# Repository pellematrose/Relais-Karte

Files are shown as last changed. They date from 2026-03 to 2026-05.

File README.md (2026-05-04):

# Relais-Karte

Relais-Karte für 24V-Systeme, zum schalten von induktiven Lasten.

---

## 🔧 Gedachte Verwendung

Über **J1** wird die Schaltung mit Strom versorgt.  
Über **J2** kann eine weitere Platine mit Spannung versorgt werden.

Eine **Autosicherung** schützt die Schaltung bzw. die angeschlossene Last.

Der **Schiebeschalter** ermöglicht es, die Last **unabhängig vom Relais** einzuschalten.

---

## 💡 Statusanzeigen (LEDs)

Die Platine verfügt über **zwei LEDs zur Zustandsanzeige**:

- **LED 1 – Versorgung & Sicherung OK**  
  - Leuchtet, wenn **Spannung anliegt** und die **Sicherung in Ordnung** ist

- **LED 2 – Relais aktiv / Last versorgt**  
  - Leuchtet, wenn das **Relais geschaltet hat** oder der **manuelle Schalter** eingeschaltet ist  
  - → Die angeschlossene **Last erhält Spannung**

---

## ⚙️ Relaissteuerung

An **J4** wird das **Schaltsignal** angeschlossen, mit dem das Relais aktiviert wird.  
Hier kann z. B. ein **Schwimmerschalter** als Schließer verwendet werden.  
Wird ein anderes externes Schaltsignal verwendet, muss auf den GND Pfad geachtet werden!

---

## 🔌 Anschluss der Last

Die Last (z. B. eine **Pumpe**) wird an **J3** angeschlossen.

### Betriebsarten:

- **Relais schaltet EIN (NO - Normally Open):**  
  - Last zwischen **NO (+24V)** und **GND** anschließen  
  - → Last ist aktiv, wenn das Relais angezogen ist

- **Relais schaltet AUS (NC - Normally Closed):**  
  - Last zwischen **NC (+24V)** und **GND** anschließen  
  - → Last ist aktiv, wenn das Relais **nicht** angezogen ist

💡 Es können auch **zwei Lasten gleichzeitig angeschlossen** werden:  
- Eine an **NO**
- Eine an **NC**  
→ Es ist dabei **immer nur eine Last aktiv**  
→ Die Last muss **immer** mit **GND** verbunden werden!

### Anschlussplan
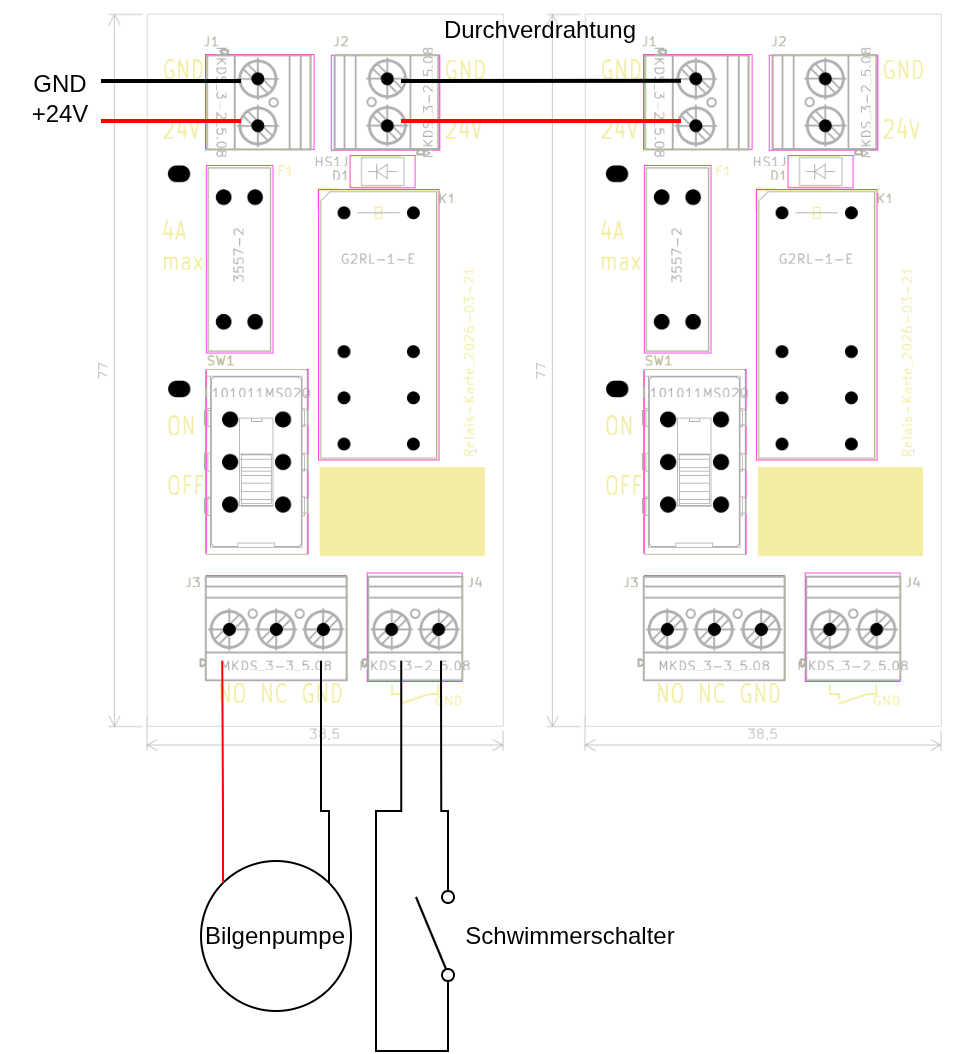
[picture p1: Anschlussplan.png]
Anschlussplan
  

---

## 📝 Sonstiges

Das **weiße Feld** auf der Platine ist für Notizen vorgesehen, z. B.:

- Nummerierung
- Bezeichnung der angeschlossenen Last

---

## 📏 Technische Daten

- Versorgungsspannung: 24V (+-20%)
- Laststrom: 4A (Schiebeschalter, Leiterbahnen)
- **PCB Maße:** 38,5 mm × 77 mm

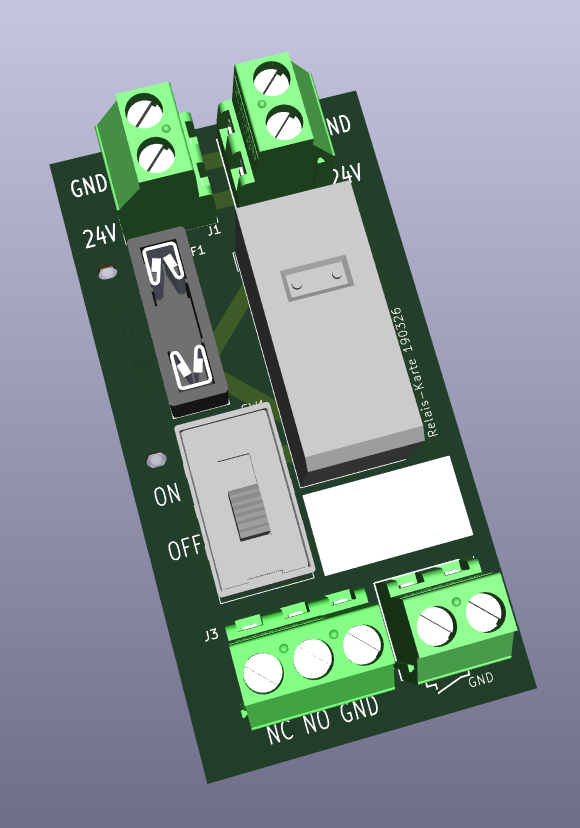
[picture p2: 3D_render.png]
3D Render

---

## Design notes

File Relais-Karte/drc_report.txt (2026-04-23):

** Drc report for Relais-Karte.kicad_pcb **
** Created on 2026-04-23T21:58:57 **
** Report includes: Errors, Warnings **

** Found 4 DRC violations **
[copper_edge_clearance]: Platinenkanten-Freiraum-Verstoß (Einschränkungen aus Platinenkonfiguration zum Rand Freiraum 0,5000 mm; tatsächlich 0,1750 mm)
    Rule: Einschränkungen aus Platinenkonfiguration zum Rand; error
    @(97.9750 mm, 54.2375 mm): NPTH-Pad von D2
    @(97.9750 mm, 52.6875 mm): Pad 1 [GND] von D2 auf B.Cu
[copper_edge_clearance]: Platinenkanten-Freiraum-Verstoß (Einschränkungen aus Platinenkonfiguration zum Rand Freiraum 0,5000 mm; tatsächlich 0,1750 mm)
    Rule: Einschränkungen aus Platinenkonfiguration zum Rand; error
    @(97.9750 mm, 54.2375 mm): NPTH-Pad von D2
    @(97.9750 mm, 55.7875 mm): Pad 2 [Net-(D2-A)] von D2 auf B.Cu
[copper_edge_clearance]: Platinenkanten-Freiraum-Verstoß (Einschränkungen aus Platinenkonfiguration zum Rand Freiraum 0,5000 mm; tatsächlich 0,1750 mm)
    Rule: Einschränkungen aus Platinenkonfiguration zum Rand; error
    @(98.0000 mm, 77.5000 mm): NPTH-Pad von D3
    @(98.0000 mm, 75.9500 mm): Pad 1 [GND] von D3 auf B.Cu
[copper_edge_clearance]: Platinenkanten-Freiraum-Verstoß (Einschränkungen aus Platinenkonfiguration zum Rand Freiraum 0,5000 mm; tatsächlich 0,1750 mm)
    Rule: Einschränkungen aus Platinenkonfiguration zum Rand; error
    @(98.0000 mm, 77.5000 mm): NPTH-Pad von D3
    @(98.0000 mm, 79.0500 mm): Pad 2 [Net-(D3-A)] von D3 auf B.Cu

** Found 0 unconnected pads **

** Found 0 Footprint errors **

** Ignored checks **
    - Footprint has no courtyard defined
    - Track endpoint not centered on via
    - Tuning profile track geometries
    - Footprint doesn't match symbol's footprint filters
    - PTH inside courtyard
    - NPTH inside courtyard
    - Footprint component type doesn't match footprint pads

** End of Report **

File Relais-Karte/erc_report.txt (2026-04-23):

ERC report (2026-04-23T21:58:53, Encoding UTF8)
Report includes: Errors, Warnings

***** Sheet /
[power_pin_not_driven]: Input Power pin not driven by any Output Power pins
    ; warning
    @(69.85 mm, 25.40 mm): Symbol #PWR010 Pin 1 [Stromversorgung, Linie]
[power_pin_not_driven]: Input Power pin not driven by any Output Power pins
    ; warning
    @(162.56 mm, 52.07 mm): Symbol #PWR02 Pin 1 [Stromversorgung, Linie]
[power_pin_not_driven]: Input Power pin not driven by any Output Power pins
    ; warning
    @(212.09 mm, 60.96 mm): Symbol #PWR01 Pin 1 [Stromversorgung, Linie]

 ** ERC messages: 3  Errors 0  Warnings 3

 ** Ignored checks:
    - Global label only appears once in the schematic
    - Four connection points are joined together
    - SPICE model issue
    - Assigned footprint doesn't match footprint filters

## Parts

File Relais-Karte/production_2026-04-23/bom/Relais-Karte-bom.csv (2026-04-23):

Reference | QUANTITY | Value | Footprint | LCSC | Digikey | Mouser
D1,D5,D6 | 3 | HS1J | _PS_LIB_PCB:D_SMA |  | 1801-HS1JCT-ND
D2 | 1 | KPTD-3216ZGCK-01 | _PS_LIB_PCB:LED_1206_3216Metric_ReverseMount_Hole1.8x2.4mm
D3 | 1 | KPTD-3216SYCK-01 | _PS_LIB_PCB:LED_1206_3216Metric_ReverseMount_Hole1.8x2.4mm
D4 | 1 | SMAJ30A | Diode_SMD:D_SMA
F1 | 1 | 3557-2 | _PS_LIB_CON:Fuse Holder Littelfuse ATOF 287 | C19727304 | 36-3557-2-ND
J1,J2,J4 | 3 | MKDS_3-2_5.08 | _PS_LIB_CON:MKDS_3_2_508 | C475092 | 277-1027-ND
J3 | 1 | MKDS_3-3_5.08 | _PS_LIB_CON:MKDS_3_3_508 | C475093 | 277-1028-ND
K1 | 1 | G2RL-1-E | _PS_LIB_PCB:Relay_SPDT_Omron_G2RL-1-E |  | Z2835-ND
Q1,Q2 | 2 | BC846 | Package_TO_SOT_SMD:SOT-23
R1,R4 | 2 | 22K | Resistor_SMD:R_0603_1608Metric | C31850
R2 | 1 | 10K | Resistor_SMD:R_0603_1608Metric | C25804
R3 | 1 | 4K7 | Resistor_SMD:R_0603_1608Metric | C23162
R5 | 1 | 100K | Resistor_SMD:R_0603_1608Metric | C25803
SW1 | 1 | L101011MS02Q | _PS_LIB_MECH:L10101_Schiebeschalter |  | CKC5106-ND
U1,U2 | 2 | TS431ACX RF | Package_TO_SOT_SMD:SOT-23 |  |  | 821-TS431ACXRFG

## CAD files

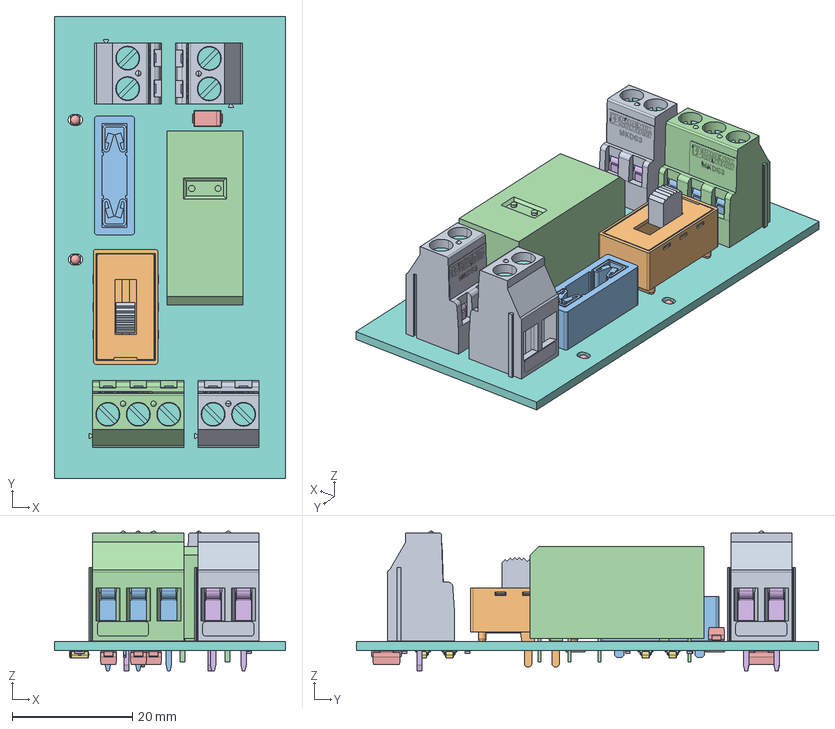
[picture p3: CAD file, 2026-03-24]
Relais-Karte/production_2026-03-24/step/Relais-Karte.step
38.5 x 77.0 x 23.3 mm
L101011MS02Q_PART1
G2RL-1-E DC24
D_SMA x 4
Bohrloch.2 x 3
Klemmhülse_1 x 3
Schraube_2 x 3
Druckstück_2 x 3
MKDS_3_3-5.08_GEH
KPTD-3216SECK x 2
R_0603_1608Metric x 5
SOT-23 x 4
Relais-Karte_PCB

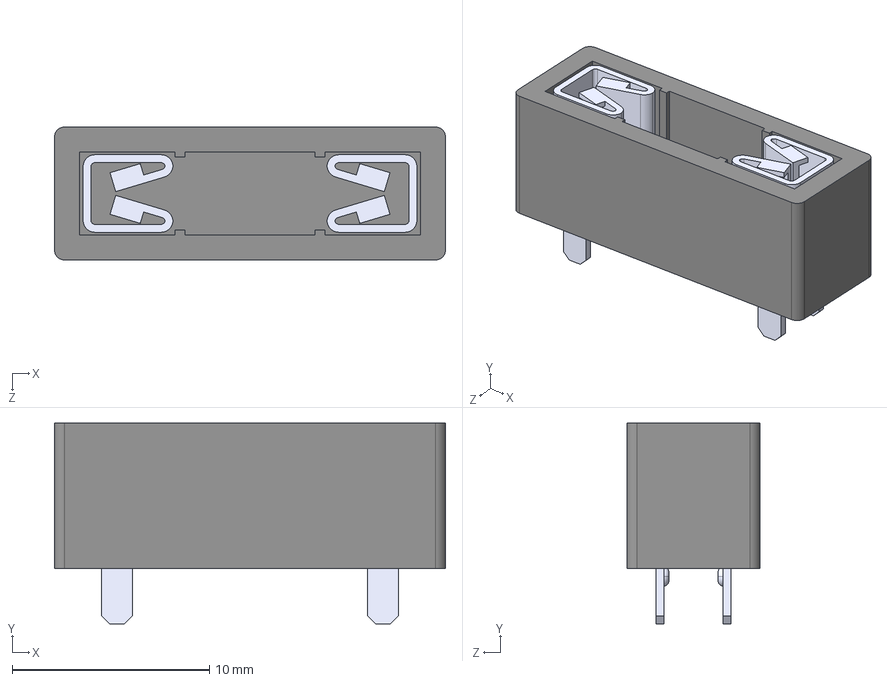
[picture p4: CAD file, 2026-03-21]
Relais-Karte/source_2026-04-23/3dmodels/3557-2.step
19.8 x 10.2 x 6.73 mm

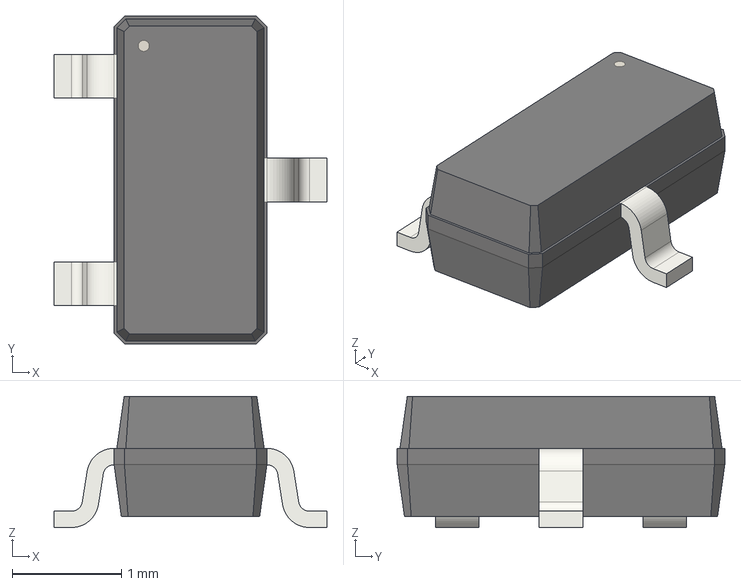
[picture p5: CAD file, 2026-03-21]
Relais-Karte/source_2026-04-23/3dmodels/SOT-23.step
2.50 x 3.00 x 1.20 mm

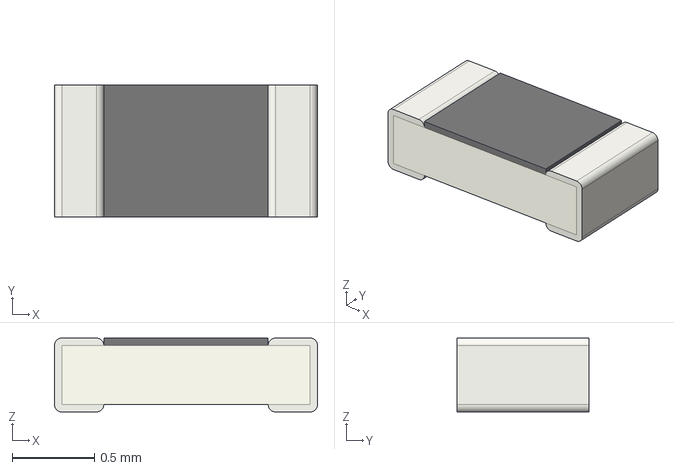
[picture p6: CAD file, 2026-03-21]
Relais-Karte/source_2026-04-23/3dmodels/R_0603_1608Metric.step
1.60 x 0.8 x 0.45 mm

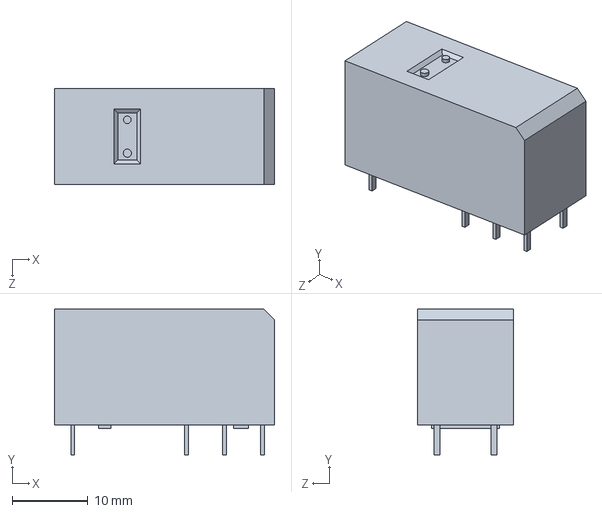
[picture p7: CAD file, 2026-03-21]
Relais-Karte/source_2026-04-23/3dmodels/G2RL-1-E DC24.STEP
29.0 x 19.2 x 12.7 mm

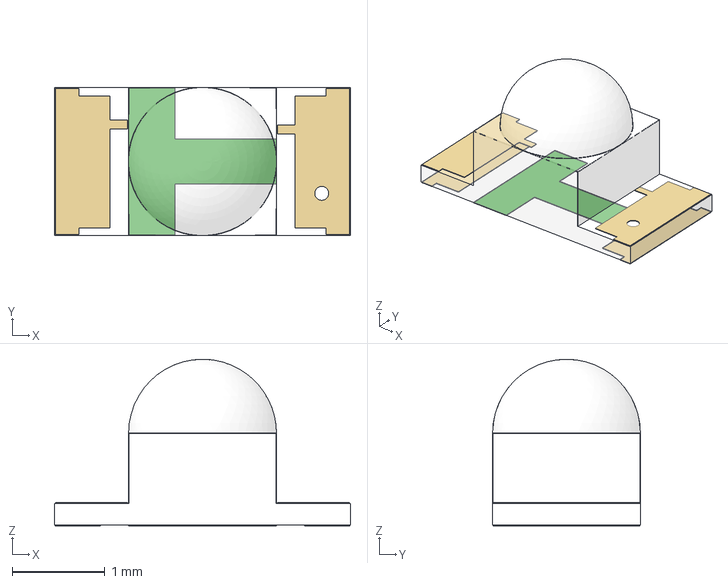
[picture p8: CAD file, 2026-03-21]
Relais-Karte/source_2026-04-23/3dmodels/KPTD-3216SECK.stp
3.20 x 1.60 x 1.80 mm

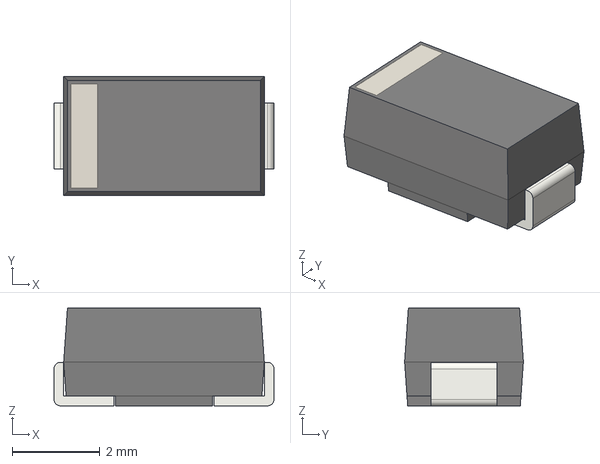
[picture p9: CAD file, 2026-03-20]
Relais-Karte/source_2026-04-23/3dmodels/D_SMA.step
5.00 x 2.70 x 2.22 mm

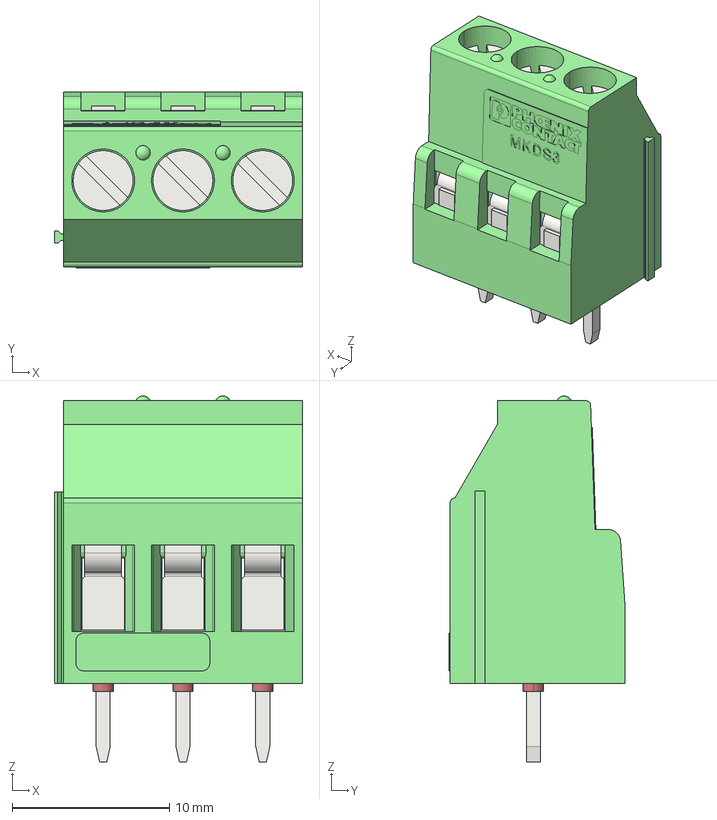
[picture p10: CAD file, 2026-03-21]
Relais-Karte/source_2026-04-23/3dmodels/1711738_06_01_MKDS-3-3-5-08_3D.stp
15.8 x 11.2 x 23.3 mm
Bohrloch.2 x 3
Klemmhülse_1 x 3
Schraube_2 x 3
Druckstück_2 x 3
MKDS_3_3-5.08_GEH

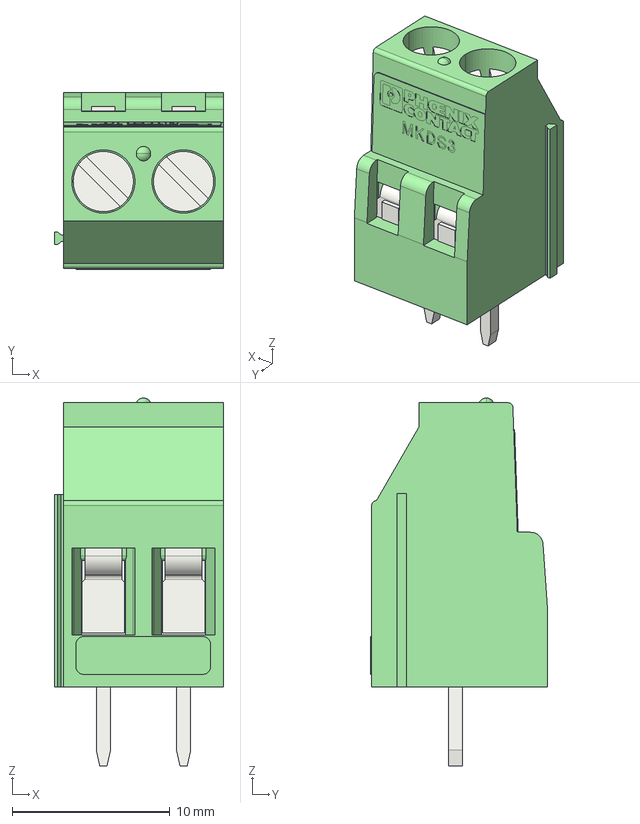
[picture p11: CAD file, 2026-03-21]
Relais-Karte/source_2026-04-23/3dmodels/1711725_06_00_MKDS-3-2-5-08_3D.stp
10.7 x 11.2 x 23.3 mm

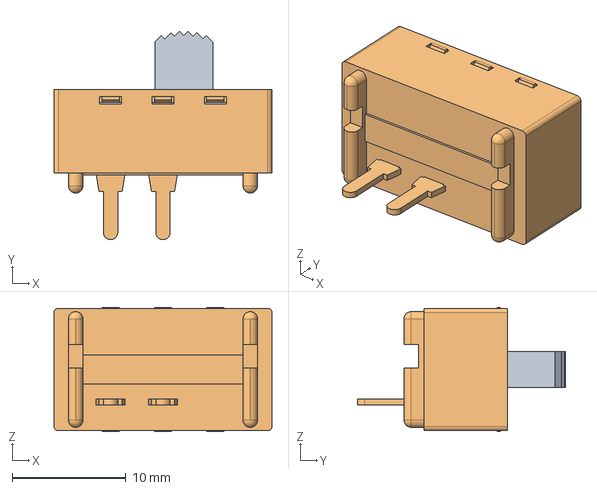
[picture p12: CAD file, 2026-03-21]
Relais-Karte/source_2026-04-23/3dmodels/L101011MS02Q_schiebeschalter.stp
19.1 x 18.3 x 10.9 mm

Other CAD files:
Relais-Karte/production_2026-04-23/step/Relais-Karte.step

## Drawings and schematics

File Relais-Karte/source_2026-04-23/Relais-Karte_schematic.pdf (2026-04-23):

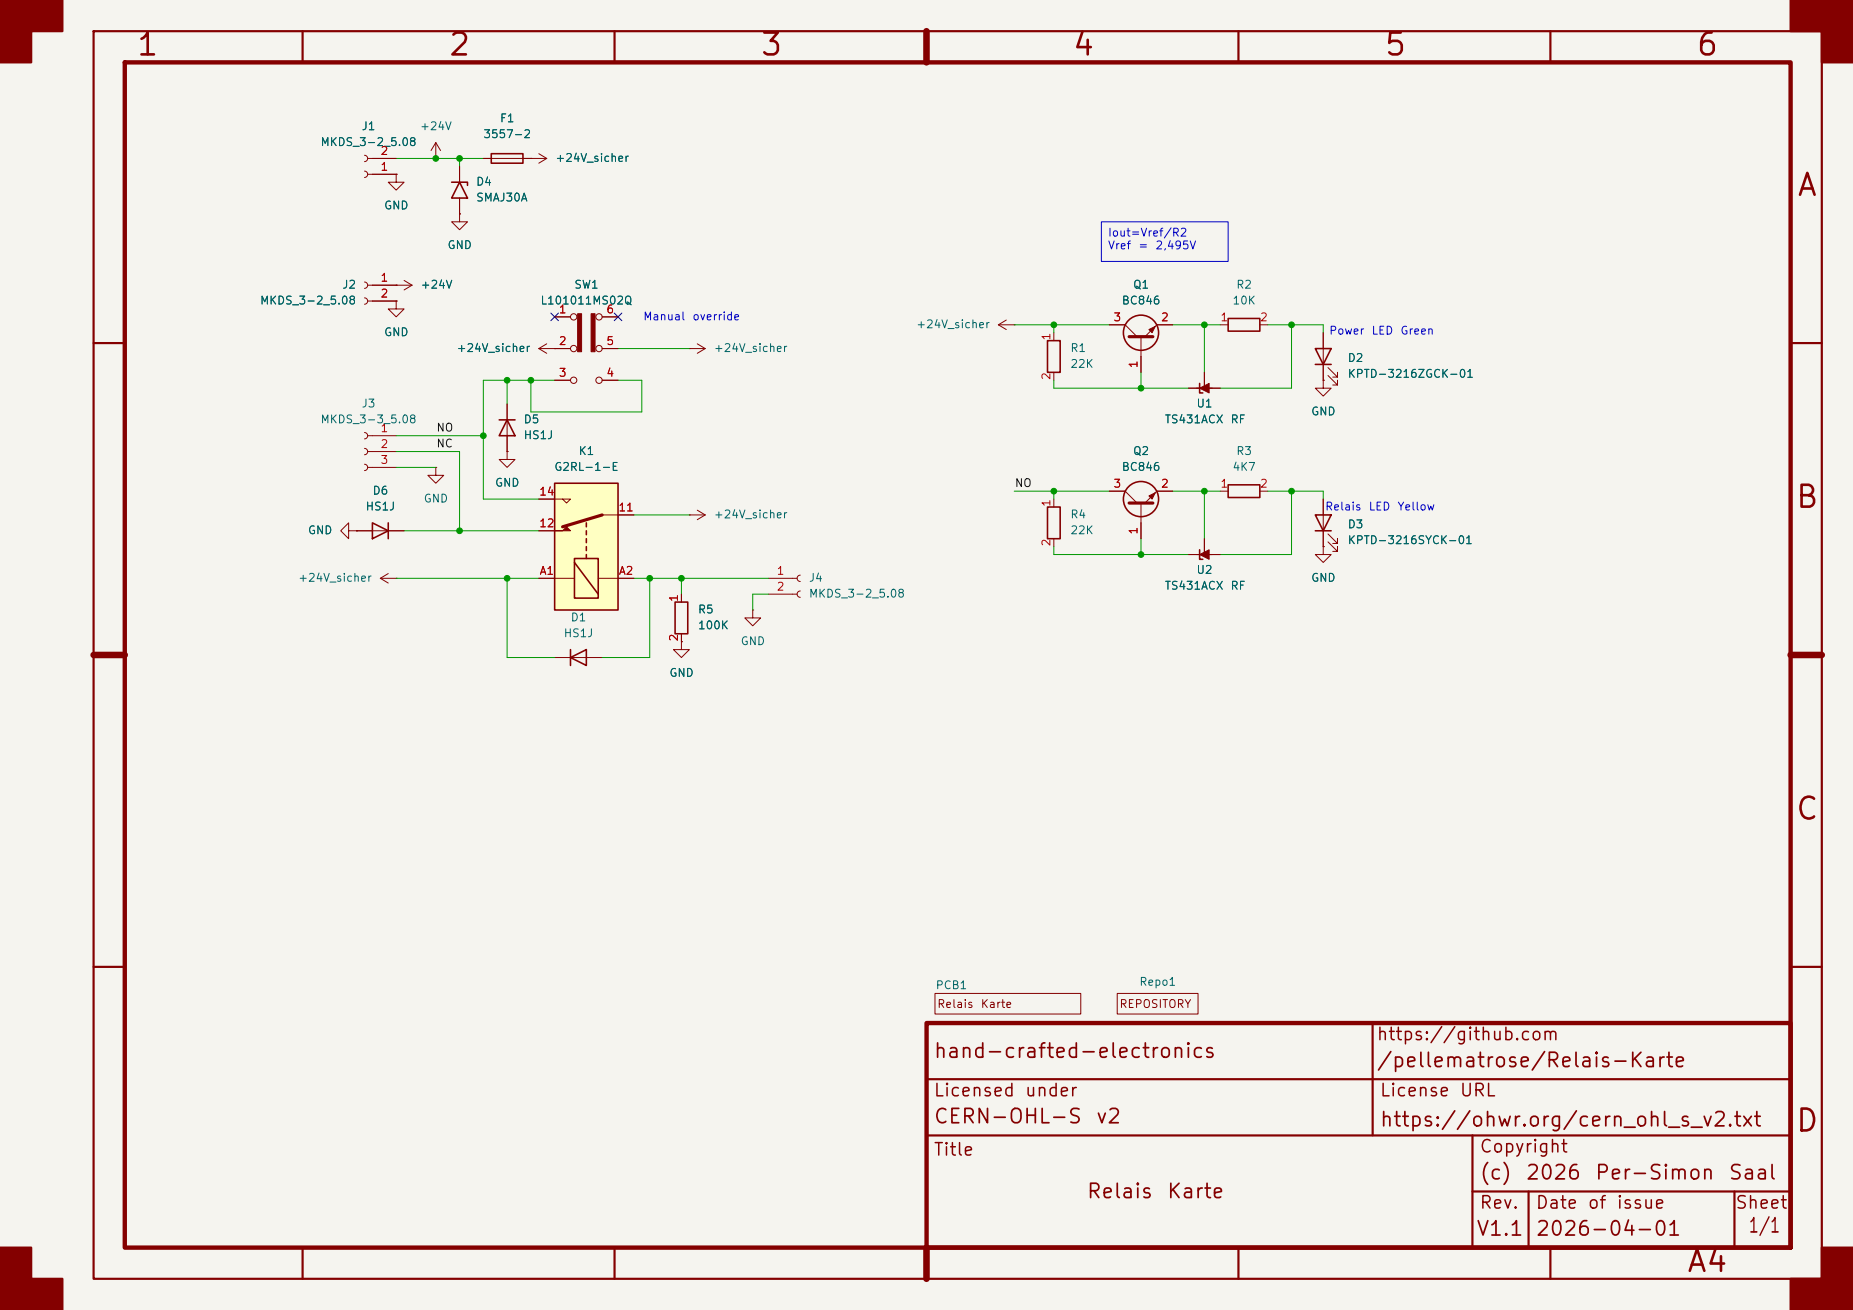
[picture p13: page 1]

hand-crafted-electronics | https://github.com/pellematrose/Relais-Karte

Licensed under CERN-OHL-S v2 | License URL https://ohwr.org/cern_ohl_s_v2.txt

Title Relais Karte | Copyright (c) 2026 Per-Simon Saal

Rev. V1.1 | Date of issue 2026-04-01 | Sheet 1/1

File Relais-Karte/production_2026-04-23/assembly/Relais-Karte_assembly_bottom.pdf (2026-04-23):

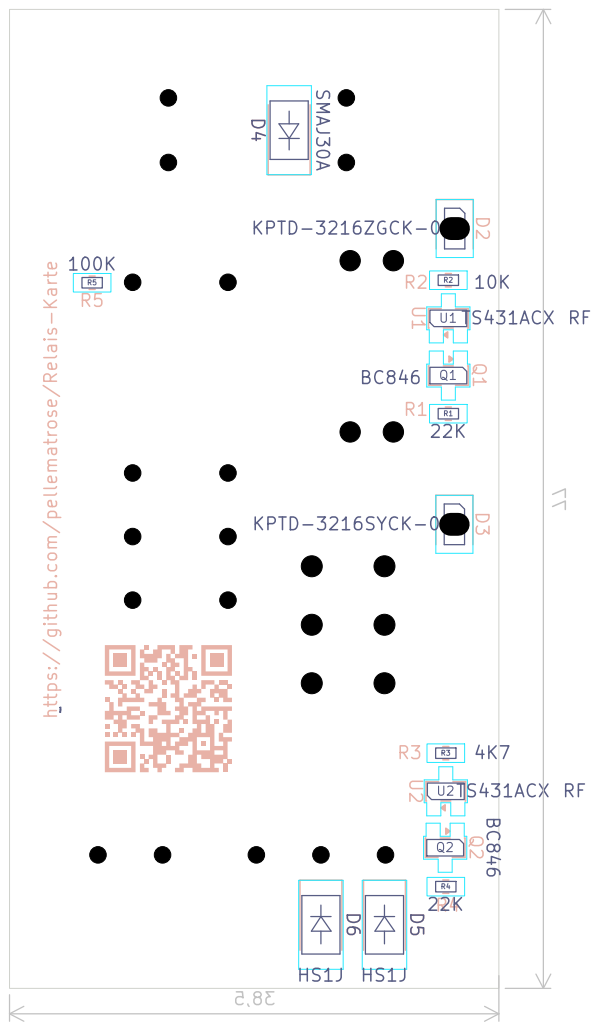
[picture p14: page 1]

hand-crafted-electronics | https://github.com/pellematrose/Relais-Karte

Licensed under Licensed under CERN-OHL-S v2 | License URL https://ohwr.org/cern_ohl_s_v2.txt

Title Relais-Karte | © 2026 Per-Simon Saal

Rev. V1.1 | Date of issue 2026-03-21 | Sheet 1/1

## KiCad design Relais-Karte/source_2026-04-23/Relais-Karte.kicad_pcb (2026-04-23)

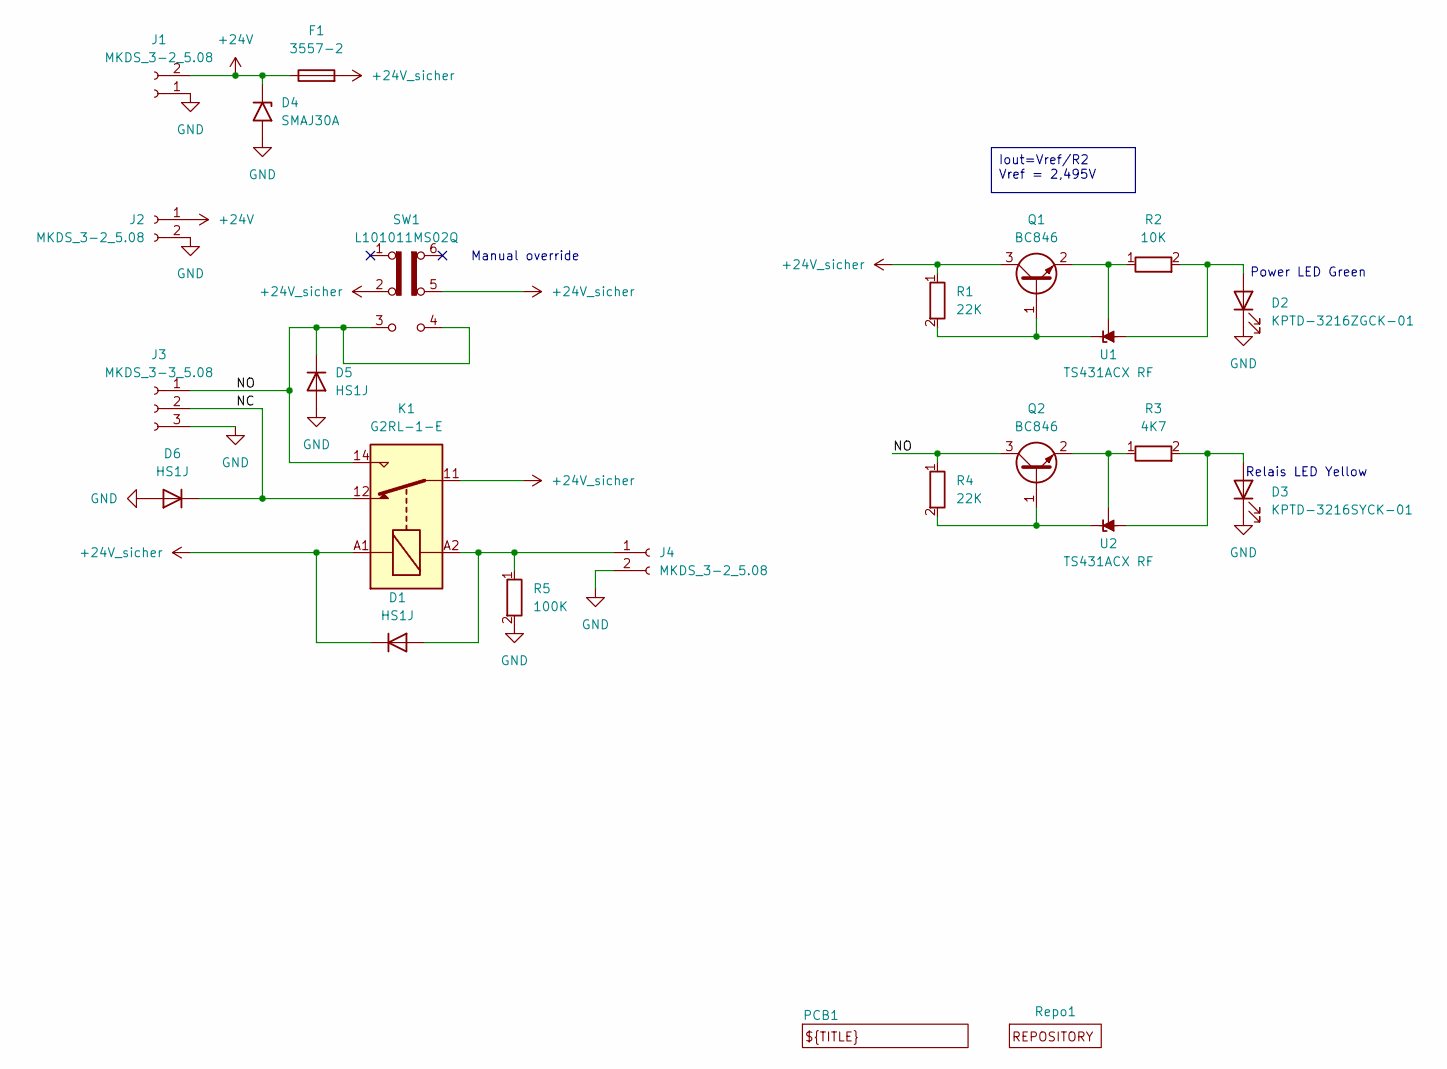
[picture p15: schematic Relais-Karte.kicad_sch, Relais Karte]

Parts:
D1, D5, D6: HS1J; D_SMA; Digikey 1801-HS1JCT-ND
D2: KPTD-3216ZGCK-01; LED_1206_3216Metric_ReverseMount_Hole1.8x2.4mm
D3: KPTD-3216SYCK-01; LED_1206_3216Metric_ReverseMount_Hole1.8x2.4mm
D4: SMAJ30A; D_SMA
F1: 3557-2; Fuse Holder Littelfuse ATOF 287; Digikey 36-3557-2-ND
J1, J2, J4: MKDS_3-2_5.08; MKDS_3_2_508; Digikey 277-1027-ND
J3: MKDS_3-3_5.08; MKDS_3_3_508; Digikey 277-1028-ND
K1: G2RL-1-E; Relay_SPDT_Omron_G2RL-1-E; Digikey Z2835-ND
PCB1: _PCB
Q1, Q2: BC846; SOT-23
R1, R4: 22K; R_0603_1608Metric; LCSC C31850
R2: 10K; R_0603_1608Metric; LCSC C25804
R3: 4K7; R_0603_1608Metric; LCSC C23162
R5: 100K; R_0603_1608Metric; LCSC C25803
Repo1: _Repository
SW1: L101011MS02Q; L10101_Schiebeschalter; Digikey CKC5106-ND
U1, U2: TS431ACX RF; SOT-23; Mouser 821-TS431ACXRFG

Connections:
+24V: D4.1 (A1), F1.1, J1.2, J2.1
+24V_sicher: D1.1 (K), F1.2, K1.11, K1.A1, Q1.3 (C), R1.1, SW1.2 (B), SW1.5 (B)
/NC: D6.1 (K), J3.2, K1.12
/NO: D5.1 (K), J3.1, K1.14, Q2.3 (C), R4.1, SW1.3 (C), SW1.4 (A)
GND: D2.1 (K), D3.1 (K), D4.2 (A2), D5.2 (A), D6.2 (A), J1.1, J2.2, J3.3, J4.2, R5.2
unnamed: D1.2 (A), J4.1, K1.A2, R5.1
unnamed: D2.2 (A), R2.2, U1.3 (A)
unnamed: D3.2 (A), R3.2, U2.3 (A)
unnamed: Q1.1 (B), R1.2, U1.2 (K)
unnamed: Q1.2 (E), R2.1, U1.1 (REF)
unnamed: Q2.1 (B), R4.2, U2.2 (K)
unnamed: Q2.2 (E), R3.1, U2.1 (REF)

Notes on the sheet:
Manual override
Relais LED Yellow
Power LED Green
Iout=Vref/R2 Vref = 2,495V

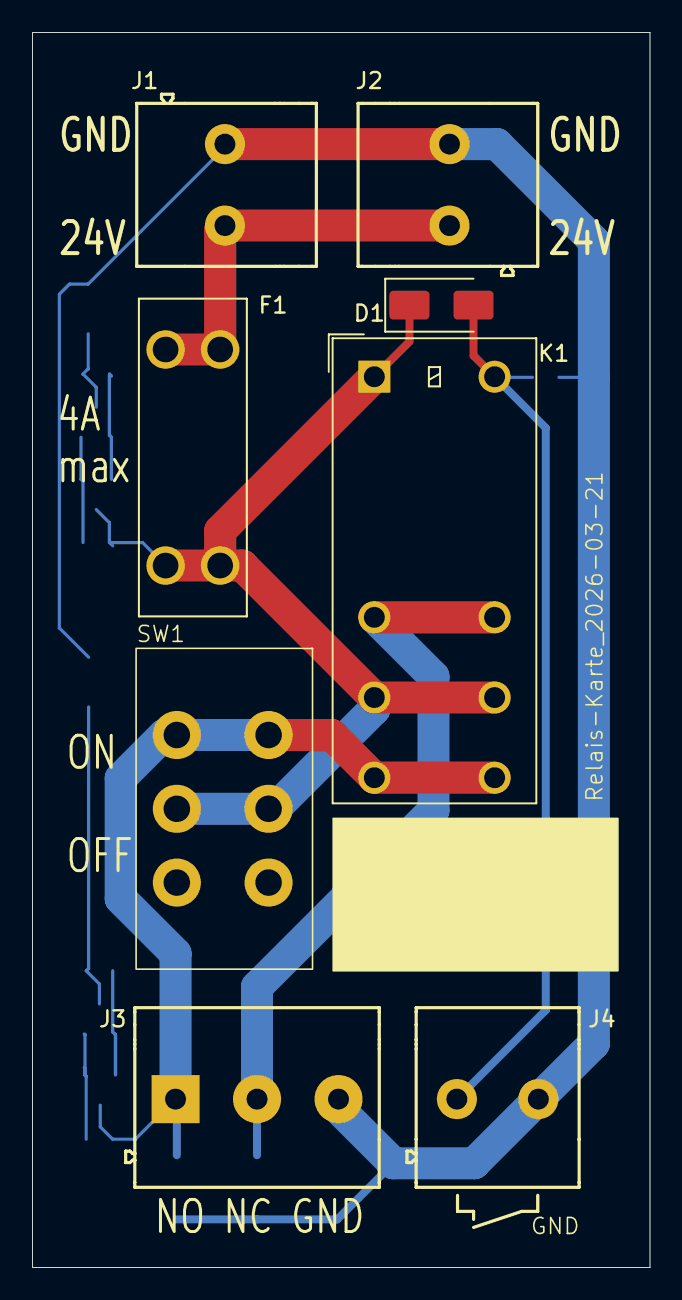
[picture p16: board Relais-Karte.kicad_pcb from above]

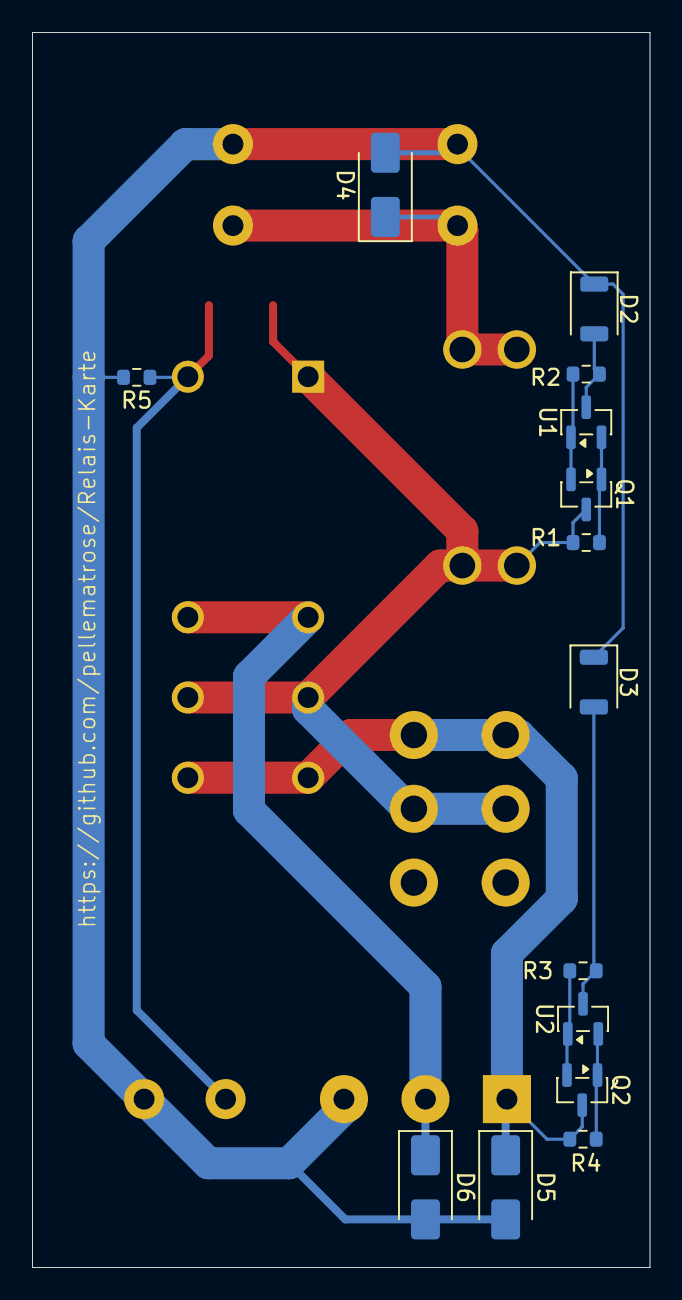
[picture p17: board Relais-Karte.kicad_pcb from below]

Board: 2 copper layers, 38.5 x 77.0 mm, 24 parts (15 on the bottom side), 12 nets.

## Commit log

2026-03-19 v0.1
    erc / drc 0 errors
    [Relais-Karte-B_Courtyard.gbr, Relais-Karte-B_Cu.gbl, Relais-Karte-B_Fab.gbr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]
2026-03-21 leds added
    [1711725_06_00_MKDS-3-2-5-08_3D.stp, 1711738_06_01_MKDS-3-3-5-08_3D.stp, 3557-2.step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]
2026-03-22 länge der platine angepasst
    [Relais-Karte-B_Courtyard.gbr, Relais-Karte-B_Cu.gbl, Relais-Karte-B_Fab.gbr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]
2026-03-23 added gerber zip file
    [1711725_06_00_MKDS-3-2-5-08_3D.stp, 1711738_06_01_MKDS-3-3-5-08_3D.stp, 3557-2.step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]
2026-03-23 led typ angepasst
    [Relais-Karte-B_Cu.gbl, Relais-Karte-B_Mask.gbs, Relais-Karte-B_Paste.gbp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]
2026-04-05 final version
    [1711725_06_00_MKDS-3-2-5-08_3D.stp, 1711738_06_01_MKDS-3-3-5-08_3D.stp, 3557-2.step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]
2026-04-23 error fixing V1.1
    D1 fixed polarity
    Silk: NC <-> NO
    LED resistors value updated
    U3, U4 -> TS431ACX RF
    [1711725_06_00_MKDS-3-2-5-08_3D.stp, 1711738_06_01_MKDS-3-3-5-08_3D.stp, 3557-2.step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]

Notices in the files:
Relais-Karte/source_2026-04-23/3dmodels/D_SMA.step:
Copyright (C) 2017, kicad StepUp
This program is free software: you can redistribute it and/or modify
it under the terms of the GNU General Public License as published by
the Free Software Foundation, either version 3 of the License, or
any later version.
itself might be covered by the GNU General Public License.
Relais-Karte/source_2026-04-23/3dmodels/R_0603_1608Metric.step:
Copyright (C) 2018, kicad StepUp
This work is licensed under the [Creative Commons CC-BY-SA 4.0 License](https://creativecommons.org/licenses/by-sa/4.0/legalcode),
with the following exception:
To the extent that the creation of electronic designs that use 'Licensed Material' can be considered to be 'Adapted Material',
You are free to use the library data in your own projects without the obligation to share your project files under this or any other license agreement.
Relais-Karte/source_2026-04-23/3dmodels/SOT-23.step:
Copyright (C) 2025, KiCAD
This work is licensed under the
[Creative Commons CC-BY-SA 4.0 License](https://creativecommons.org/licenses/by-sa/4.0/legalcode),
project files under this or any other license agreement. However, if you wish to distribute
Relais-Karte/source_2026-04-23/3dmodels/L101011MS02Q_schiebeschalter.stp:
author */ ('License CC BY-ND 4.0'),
